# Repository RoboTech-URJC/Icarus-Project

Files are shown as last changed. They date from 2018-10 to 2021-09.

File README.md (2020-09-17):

# Drone Icarus

&nbsp;


&nbsp;


## Description

It is an autonomous drone which is able of avoiding obstacles and detecting other drones. The main functionality of this drone is being able to shoot down others drones on flight

## Contributions Guidelines

Do you want to contribute to our project? Check out our guidelines before you contribute: CONTRIBUTING

<p align="center">
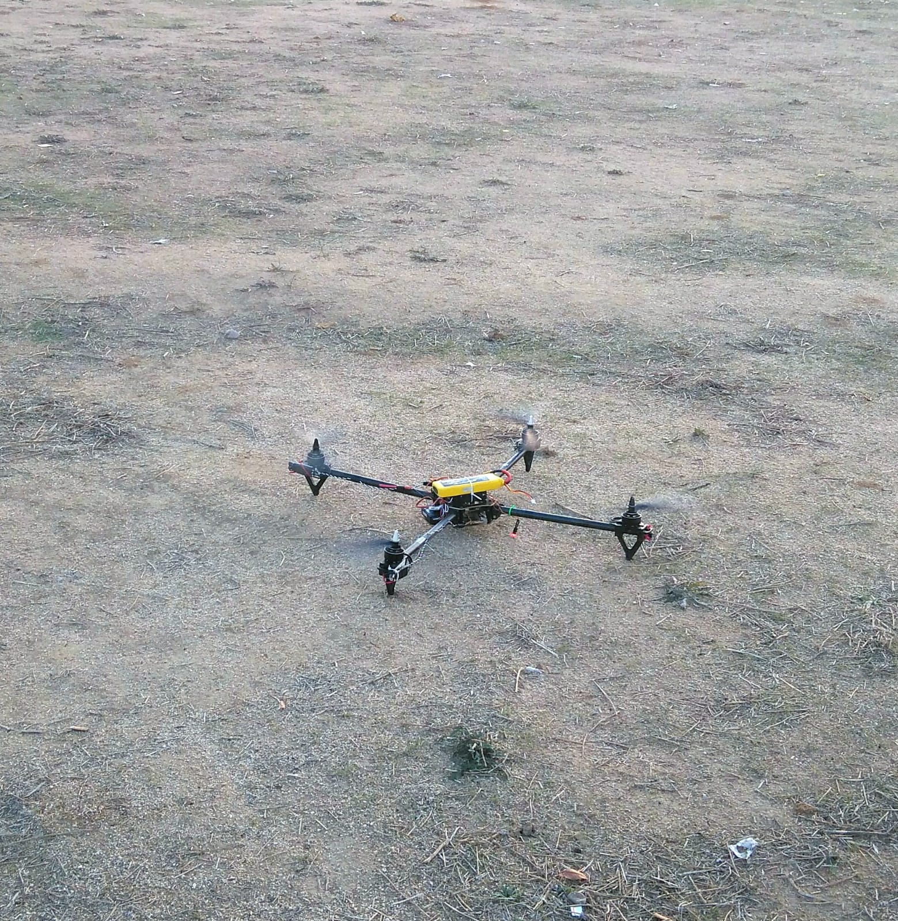
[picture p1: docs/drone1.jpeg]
  
</p>

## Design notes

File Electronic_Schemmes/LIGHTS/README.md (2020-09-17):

# Lights Controller

&nbsp;
&nbsp;

Lights controller has been complete designed for controlling 4 RGB LED raws by pairs (head and tail of the drone), in order to provide a better ground-air visualization  with our drone and know at real time what the drone is doing inside its hardware
### Hardware
Hardware consist of a PCB, 12 transistors **2N2222** , 12 resistors **2kOhm** and **Arduino Nano** which works as the semi-embedded micro-controller
### Software
The purpose of the controller mainly is to control with PWM signal (not implemented yet) the bright of led as well as create a code of colors which allow to controllers to verify what the drone is really doing on air. Programmed in Arduino (C++) the code drives the behavior of the lights through  the serial port.

:warning: Icarus driver method to comunicate with lights controller: `void IcarusDriver::notifyAck(std::string msg)`

Lights behaviors ~ parameter of notifyAck [`std::string msg`]:

- `a`: activate mode ~ green lights
- `b`: flying mode ~ blue lights
- `c`: warning mode ~ red lights
- `p`: pulse mode ~ flash lights --- to control the interval time of each flash change the variable `int pulse_interval`
- `s`: stop mode ~ turn off all lights

### Connections
 ARDUINO PIN | COLOR LED |
----------------------|-----------|
HEAD
3 | R |
5 | G |
6 | B |
TAIL
9 | R |
10 | G |
11 | B |

<p align="center">
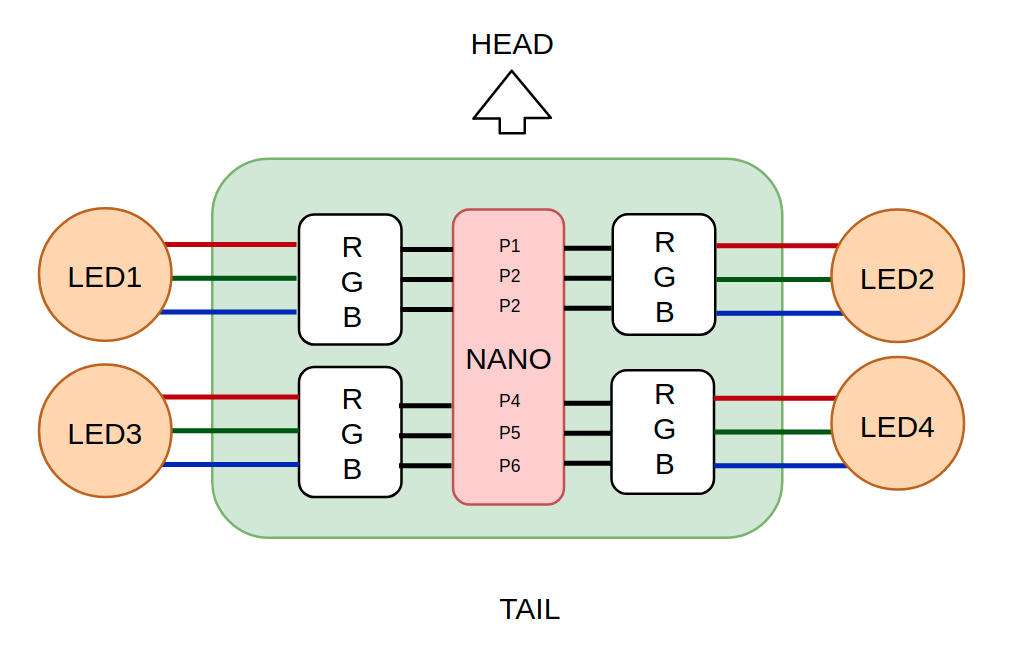
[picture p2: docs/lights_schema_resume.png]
  
</p>

 ### Designs

 - Schema

<p align="center">
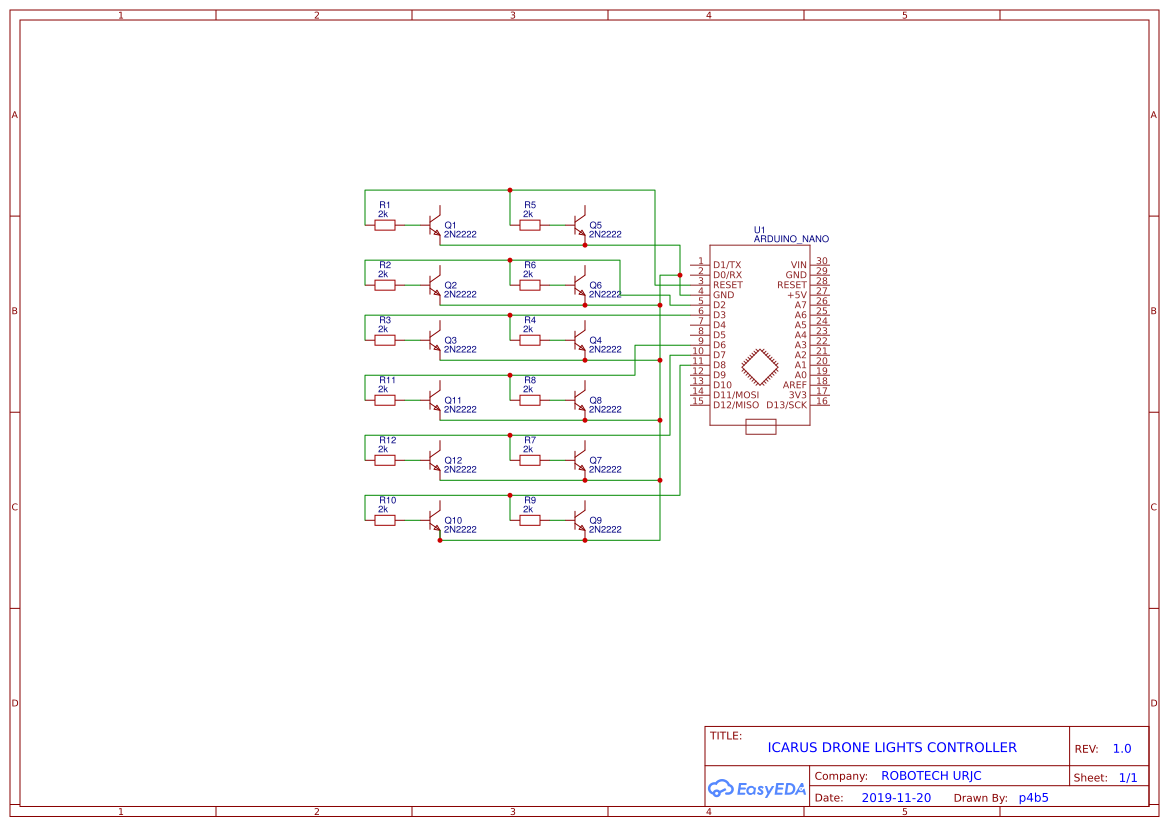
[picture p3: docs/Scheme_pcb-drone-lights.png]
  
</p>

- PCB layout

<p align="center">
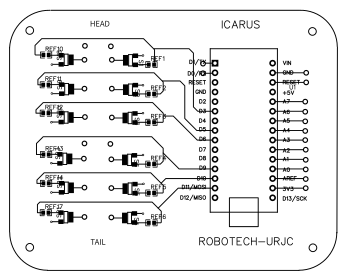
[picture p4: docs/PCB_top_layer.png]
  
</p>

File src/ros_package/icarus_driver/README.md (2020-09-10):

# ICARUS DRIVER

#### API of Icarus driver

| NAME  | DESCRIPTION | ACESS | FUNCTION |
| ---| --- | --- |--- |
| set mode  | set the mode you want to operate with the drone | `public` |`void IcarusDriver::SetMode(std::string mode)`|
| arm / disarm  | arm or disarm the drone | `public` |`void IcarusDriver::armDisarm(int arm)`|
| take off  | take off to a preorder altitude  |`public` | `void IcarusDriver::takeoff(double alt)`|
| move to local point  | move to a point in the local map | `public`|`void IcarusDriver::moveLocalTo(double x, double y,double z)`|
| turn to local point  | turn to a point in the local map | `public`|`IcarusDriver::void turnLocalTo(double roll, double pitch, double yaw);`|
| get status | get Icarus drone status |`public`|`StatusType IcarusDriver::getArmStatus()`|
| Init parameters | inicialization of parameters | `private`| `void IcarusDriver::initParams();`|
| ack notifier | notify an external serial port device |`private`|`void IcarusDriver::notifyAck(std::string msg)`|
| mavros state callback | notify an external serial port device |`private`|`void IcarusDriver::droneStateCb(const mavros_msgs::State::ConstPtr& msg);`|
| battery status callback | notify an external serial port device |`private`|`void IcarusDriver::batteryStatusCb(const sensor_msgs::BatteryState::ConstPtr& msg);`|

> TODO: emergency_land(), move_global_to(), watchdog()

#### Icarus Driver Types:

```
typedef struct StatusType StatusType;
struct StatusType
{
  bool is_armed;
  float battery_percentage;
};
```

# BOCANEGRA

Bocanegra is a state machine conceived specially for this project and addressed to give the best performace for our purpose.

<p align="center">
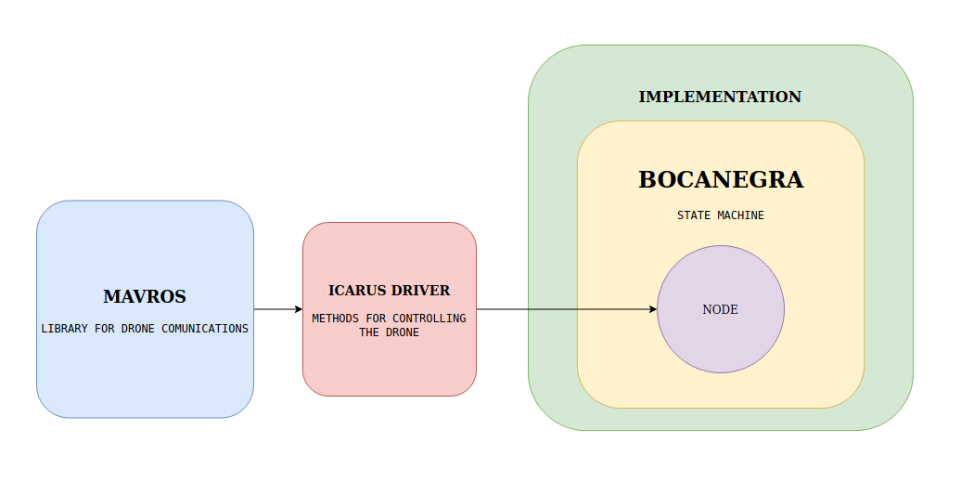
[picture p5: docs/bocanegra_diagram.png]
  
</p>

#### API of Bocanegra state machine driver

| NAME  | DESCRIPTION | ACESS | FUNCTION |
| ---| --- | --- |--- |
| is active | check if a node is active  | `protected` | `bool Bocanegra::isActive()` |
| activate  | active an inactivate node | `protected` | `void Bocanegra::activate(std::string node_name)`|
| deactivate  | deactivate a node | `protected` | `void Bocanegra::deactivate(std::string node_name)`|
| states callback | give the vector of states |`private`|`void Bocanegra::statesCallback(const boca_negra_msgs::states::ConstPtr msg)`|
| is active | check if a node is active  | `private` | `bool Bocanegra::isActive(std::string node_name)` |

#### Bocanegra messages

| NAME  | DESCRIPTION | MSGS |
| ---| --- | --- |
| state | msg with the node and its state |<p>`std_msgs/String node_name`</p> <p>`std_msgs/Bool is_active`</p>|
| states  | array with all the current node_states  | `state[] array`|

#### Bocanegra services

| NAME  | DESCRIPTION | SRV |
| ---| --- | --- |
| state_change | <p>request: node_name + state</p><p>response: node_name + new state</p>|<p>`std_msgs/String node_name`</p>`std_msgs/Bool active`<p>---</p><p>`std_msgs/String node_name`</p><p>`std_msgs/Bool active`</p>|

#### EXAMPLE

to begin to use our implementation, follow these steps:

 1. Run `~/Firmware/Tools/gazebo_sitl_multiple_run.sh -n 1`
 2. Run `roslaunch mavros px4.launch fcu_url:="udp://:14540@127.0.0.1:14557"`
 3. `roslaunch icarus_driver icarus_driver.launch`
 4. `rosrun simple_mover_drone hfsm_mover_node`

 optionally you can visualize:
 - rviz: `rosrun rviz rviz`
 - drone position: `rostopic echo /mavros/local_position/pose`

<p align="center">
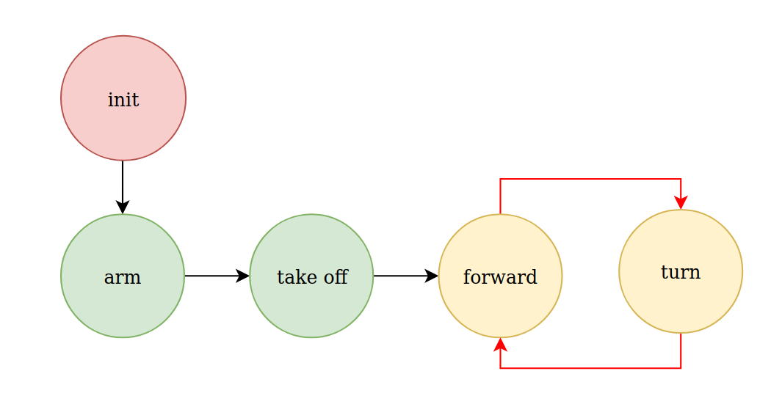
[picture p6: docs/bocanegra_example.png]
  
</p>

<p align="center">
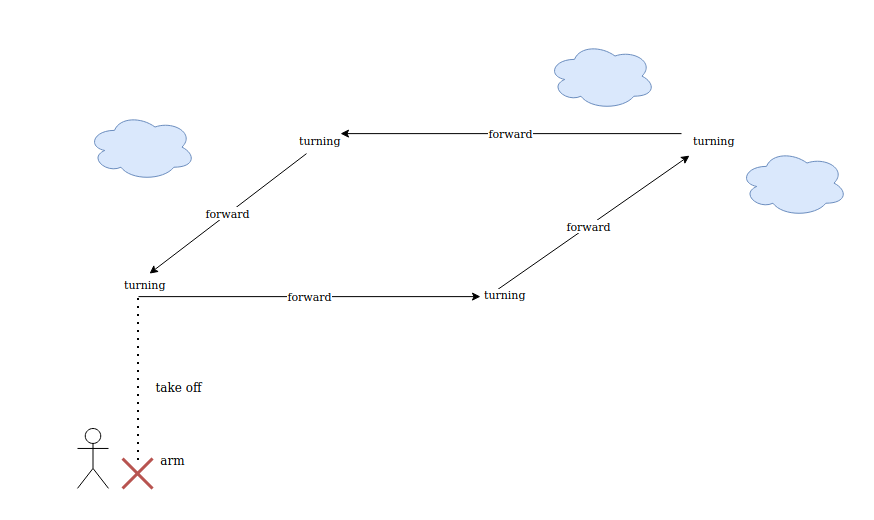
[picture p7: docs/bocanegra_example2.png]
  
</p>

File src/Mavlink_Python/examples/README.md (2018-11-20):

Here there are diferent example applications that uses the driver 'driver-icarus.py'.
* ["application1.py" demo:](https://www.youtube.com/watch?v=0h_9_rxgOh0&t=25s) Demostration with simulated drone.

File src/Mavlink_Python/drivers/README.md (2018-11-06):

# Description
It is about the driver that control all functionalities of Icarus

# Usage and Functionality of Main Methods
Here is explained the main methods used in the driver 'driver-icarus.py' included in pymavlink library.
## mavutil.mavlink_connection(port)
This method serves to open a serial, UDP, TCP or file mavlink connection, where "port" is the serial device or 
the UDP ot TCP end point. In each case, port value is:
* **Serial Device:** '/dev/ttyX'
* **End Point:** 'udpin:IP:Port' for UDP connection; or 'tcpin:IP:Port' for tcp connection. 
Example:
```
ardupilot = mavutil.mavlink_connection('udpin:localhost:14551')
```
This method can also receive more parameter that in case thay are not given, thay have a default value. The header of this method is the next one:
```
def mavlink_connection(device, baud=115200, source_system=255, source_component=0,
                       planner_format=None, write=False, append=False,
                       robust_parsing=True, notimestamps=False, input=True,
                       dialect=None, autoreconnect=False, zero_time_base=False,
                       retries=3, use_native=default_native,
                       force_connected=False, progress_callback=None):
```

## recv_match()
Receive the next MAVLink message. It can receive parameters or not. His header is the next one:
```
def recv_match(self, condition=None, type=None, blocking=False, timeout=None):
```
In this case, we use that method to receive the initial parameters of configuration of the drone. This type of message is called "HEARTBEATE", so, if we want to receive this parameter, the sentence to do this will be                                              
``msg = ardupilot.recv_match(type='HEARTBEAT', blocking=True)``. The parameter "blocking" serves to make that the call to this method blocking. 

## recv_msg()
Receive any message from the drone. Example:
```
msg = self.ardupilot.recv_msg()
print msg
```
We can put this code into a loop to read every time the messages the drone sends.

## mav.heartbeat_send()
This method is very important because it serves to coordinate the pc with the drone. That function send a hearbeat message to the drone of the samme way that drone sended it to us and we could to read it using the method "recv_match()" previously mentioned. It is very important that the parameters we send to the drone with this method are the same. The header of this methos is as follows:
```
self.ardupilot.mav.heartbeat_send(type, autopilot, base_mode, custom_mode, system_status, mavlink_version)
```
You can see which are these parameters using the previous function as follows:
```
msg = ardupilot.recv_match(type='HEARTBEAT', blocking=True)
print(msg)
```
## set_mode_apm(mode)
This method serves to set the flight mode of the drone to any of different modes that exist. That modes are:

| Mode | Summary |
| ---- | --- |
| Acro |  Holds attitude, no self-level |
| Alt Hold |  Holds altitude and self-levels the roll & pitch |
| Auto |  Executes pre-defined mission |
| AutoTune |  Executes pre-defined mission |
| Brake |  Brings copter to an immediate stop |
| Circle |  Automatically circles a point in front of the vehicle |
| Drift |  Like stabilize, but coordinates yaw with roll like a plane |
| Flip |  Rises and completes an automated flip |
| FlowHold |  Position control using Optical Flow |
| Follow |  Follows another vehicle |
| Guided |  Navigates to single points commanded by GCS |
| Land |  Reduces altitude to ground level, attempts to go straight down |
| Loiter |  Holds altitude and position, uses GPS for movements |
| PosHold |  Like loiter, but manual roll and pitch when sticks not centered |
| RTL |  Retruns above takeoff location, may aslo include landing |
| SmartRTL |  RTL, but traces path to get home |
| Stabilize |  Self-levels the roll and pitch axis |
| Sport |  Alt-hold, but holds pitch & roll when sticks centered |
| Throw |  Holds position after a throwing takeoff |

For example, to change to "Guided" mode: ``ardupilot.set_mode_apm('GUIDED')`` .

## mav.command_long_send()
Serves to send commands to the drone. The parameters that it receives depend of the command type. [Here](http://ardupilot.org/planner/docs/common-mavlink-mission-command-messages-mav_cmd.html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) are every commands and his usability

# How to Receive Parameters?
To receive parameters we use ``messages[[Param type]].[match]``. For example, if we want to receive the relative altitude of the drone, we will use ``ardupilot.messages['GLOBAL_POSITION_INT'].relative_alt``

How can we know which is the param type we have tu use? We can see all the parameters that the drone sends with ``recv_msg`` inside a loop. that is an example of we receive:
```
RAW_IMU {time_usec : 2420564594, xacc : 0, yacc : 0, zacc : -1001, xgyro : 1, ygyro : 1, zgyro : 1, xmag : 194, ymag : 118, zmag : -538}
SCALED_IMU2 {time_boot_ms : 32485335, xacc : 0, yacc : 0, zacc : -1001, xgyro : 1, ygyro : 1, zgyro : 1, xmag : 194, ymag : 118, zmag : -538}
SCALED_PRESSURE {time_boot_ms : 32485335, press_abs : 945.027038574, press_diff : 0.0, temperature : 3500}
SYS_STATUS {onboard_control_sensors_present : 56753199, onboard_control_sensors_enabled : 39975983, onboard_control_sensors_health : 56753199, load : 0, voltage_battery : 12587, current_battery : 0, battery_remaining : 83, drop_rate_comm : 0, errors_comm : 0, errors_count1 : 0, errors_count2 : 0, errors_count3 : 0, errors_count4 : 0}
POWER_STATUS {Vcc : 5000, Vservo : 0, flags : 0}
MEMINFO {brkval : 0, freemem : 65535, freemem32 : 131072}
MISSION_CURRENT {seq : 0}
GPS_RAW_INT {time_usec : 32485215000, fix_type : 6, lat : -353632564, lon : 1491652320, alt : 584100, eph : 121, epv : 200, vel : 0, cog : 11789, satellites_visible : 10, alt_ellipsoid : 0, h_acc : 200, v_acc : 200, vel_acc : 40, hdg_acc : 0}
NAV_CONTROLLER_OUTPUT {nav_roll : -0.119866870344, nav_pitch : -0.117011599243, nav_bearing : -22, target_bearing : 0, wp_dist : 0, alt_error : -0.657050848007, aspd_error : 0.0, xtrack_error : 0.0}
GLOBAL_POSITION_INT {time_boot_ms : 32485335, lat : -353632563, lon : 1491652315, alt : 584010, relative_alt : 6, vx : 1, vy : -4, vz : 0, hdg : 33785}
LOCAL_POSITION_NED {time_boot_ms : 32485335, x : -0.0935497283936, y : 0.259233921766, z : -0.00685916794464, vx : 0.0173883810639, vy : -0.0487783513963, vz : 0.00074397190474}
SERVO_OUTPUT_RAW {time_usec : 2420564594, port : 0, servo1_raw : 1000, servo2_raw : 1000, servo3_raw : 1000, servo4_raw : 1000, servo5_raw : 0, servo6_raw : 0, servo7_raw : 0, servo8_raw : 0, servo9_raw : 0, servo10_raw : 0, servo11_raw : 0, servo12_raw : 0, servo13_raw : 0, servo14_raw : 0, servo15_raw : 0, servo16_raw : 0}
RC_CHANNELS {time_boot_ms : 32485335, chancount : 16, chan1_raw : 1500, chan2_raw : 1500, chan3_raw : 1000, chan4_raw : 1500, chan5_raw : 1800, chan6_raw : 1000, chan7_raw : 1000, chan8_raw : 1800, chan9_raw : 0, chan10_raw : 0, chan11_raw : 0, chan12_raw : 0, chan13_raw : 0, chan14_raw : 0, chan15_raw : 0, chan16_raw : 0, chan17_raw : 0, chan18_raw : 0, rssi : 0}
ATTITUDE {time_boot_ms : 32485335, roll : -0.00209207204171, pitch : -0.00204223790206, yaw : -0.386602848768, rollspeed : -0.000276305130683, pitchspeed : -0.000244989059865, yawspeed : -0.000729398336262}
SIMSTATE {roll : 0.0, pitch : 0.0, yaw : -0.341762781143, xacc : -2.19979159888e-10, yacc : 2.11345663192e-10, zacc : -9.80665016174, xgyro : -8.40779078595e-43, ygyro : -7.28675201449e-43, zgyro : 1.43051111081e-05, lat : -353632564, lng : 1491652320}
AHRS2 {roll : 0.00179860368371, pitch : 0.00161452894099, yaw : -0.345547944307, altitude : 0.0, lat : 0, lng : 0}
AHRS3 {roll : -0.00209207204171, pitch : -0.00204223790206, yaw : -0.386602848768, altitude : 584.010009766, lat : -353632563, lng : 1491652315, v1 : 0.0, v2 : 0.0, v3 : 0.0, v4 : 0.0}
VFR_HUD {airspeed : 0.0, groundspeed : 0.0517849698663, heading : 337, throttle : 0, alt : 584.010009766, climb : -0.00074397190474}
AHRS {omegaIx : -0.00153755501378, omegaIy : -0.00152305862866, omegaIz : -0.00194238708355, accel_weight : 0.0, renorm_val : 0.0, error_rp : 0.00235023279674, error_yaw : 0.00180114735849}
HWSTATUS {Vcc : 5000, I2Cerr : 0}
SYSTEM_TIME {time_unix_usec : 1541471159699221, time_boot_ms : 32485335}
TERRAIN_REPORT {lat : -353632563, lon : 1491652315, spacing : 100, terrain_height : 583.887329102, current_height : 0.0015869140625, pending : 0, loaded : 504}
BATTERY_STATUS {id : 0, battery_function : 0, type : 0, temperature : 32767, voltages : [12587, 65535, 65535, 65535, 65535, 65535, 65535, 65535, 65535, 65535], current_battery : 0, current_consumed : 144186, energy_consumed : 63240, battery_remaining : 83, time_remaining : 0, charge_state : 0}
```

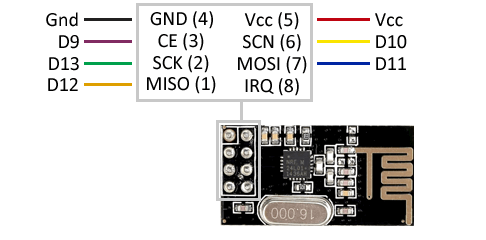
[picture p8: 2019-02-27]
Jammer/nrf24_pinout.png

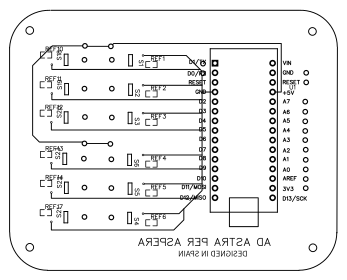
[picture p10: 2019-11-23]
docs/PCB_bottom_layer.png

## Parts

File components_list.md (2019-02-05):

| Component | Rate | Link | 
| --- | ---- | ---- |
| Orange Pi 3 | 41.05 € | [Aliexpress](https://es.aliexpress.com/store/product/Orange-Pi-3-H6-2GB-LPDDR3-8GB-EMMC-Flash-Gigabyte-Ethernet-Port-AP6256-WIFI-BT5-0/1553371_32971639306.html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,searchweb201602_2_10065_10068_10547_319_10891_317_10548_10696_10084_453_454_10083_10618_10307_10820_10821_10301_10303_537_536_10902_10059_10884_10887_321_322_10103-10891,searchweb201603_51,ppcSwitch_0&algo_expid=5c913c3a-22a4-4755-92a3-86eff891546d-0&algo_pvid=5c913c3a-22a4-4755-92a3-86eff891546d&transAbTest=ae803_4) |
| LiPo Battery | 40 € | [Amazon](https://www.amazon.es/HRB-Multicopteros-Helic%C3%B3pteros-Veh%C3%ADculo-Diversos/dp/B071GNLMPQ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) |
| GPS Antenna | 14.99 € | [Amazon](https://www.amazon.es/loonBonnie-Br%C3%BAjula-Controlador-Multicopter-Quadcopter/dp/B07M9W2NXG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) |

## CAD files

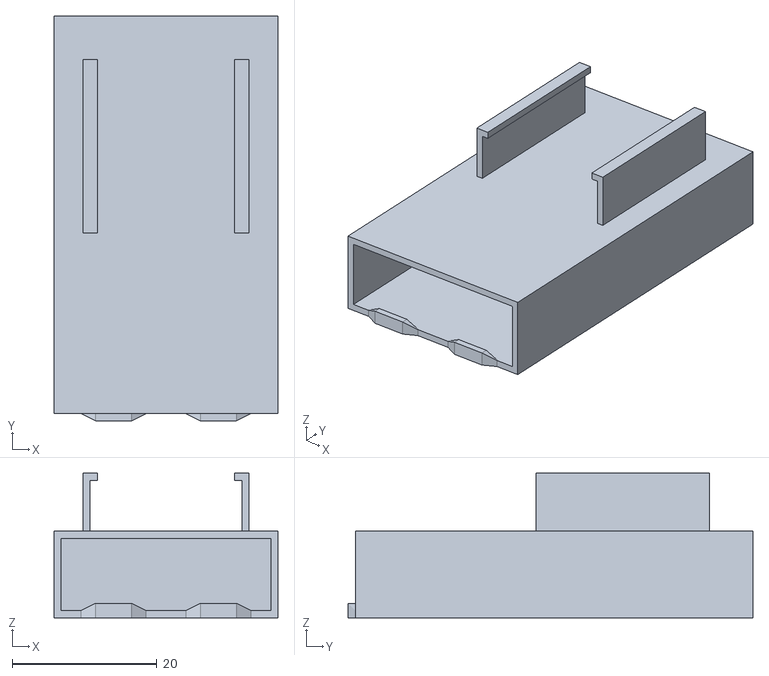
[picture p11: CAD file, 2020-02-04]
3D_print/drone_battery_holder.stl
31.0 x 56.0 x 20.0

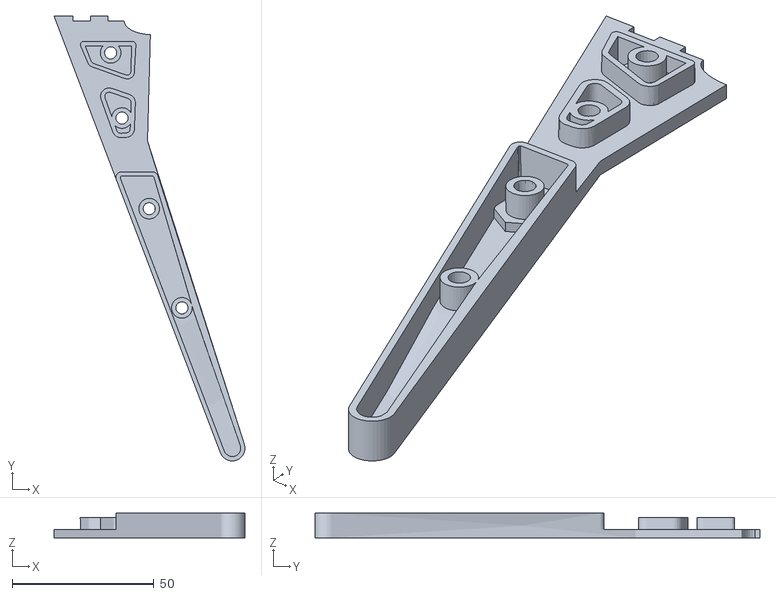
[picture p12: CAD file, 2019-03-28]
3D_print/landing gear/f550_Legs_Final.stl
67.4 x 157.0 x 8.70

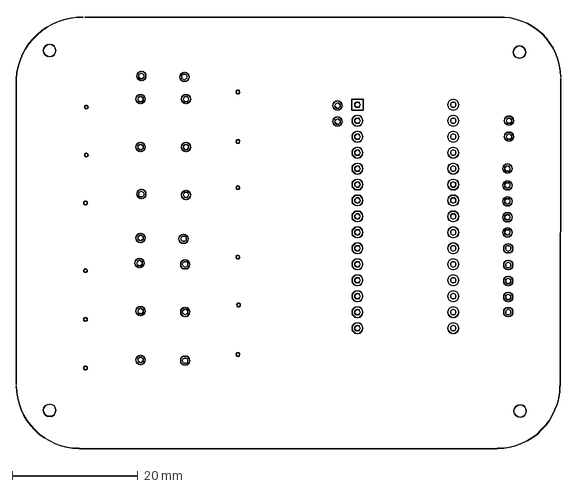
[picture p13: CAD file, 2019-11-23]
Electronic_Schemmes/LIGHTS/PCB/PCB_drone_lights.dxf
86.7 x 68.8 mm

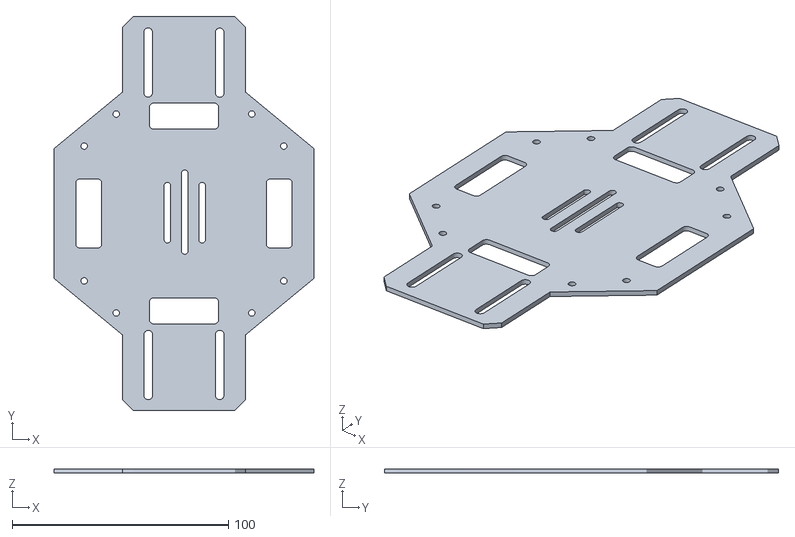
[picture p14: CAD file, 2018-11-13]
3D_print/bottom_plate.stl
120.0 x 182.0 x 2.00

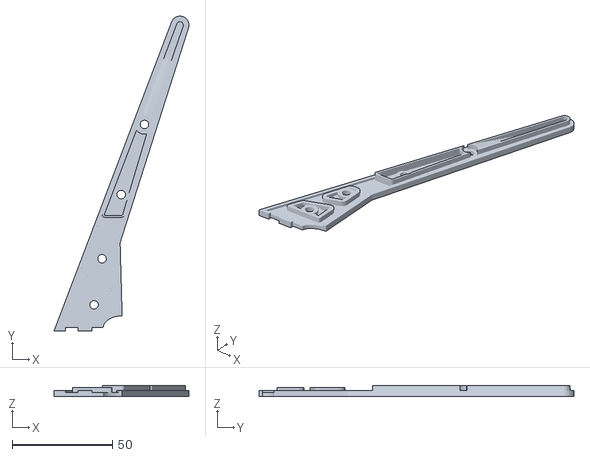
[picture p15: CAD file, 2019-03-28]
3D_print/landing gear/f550_legs_p2_final.stl
67.4 x 157.1 x 5.50

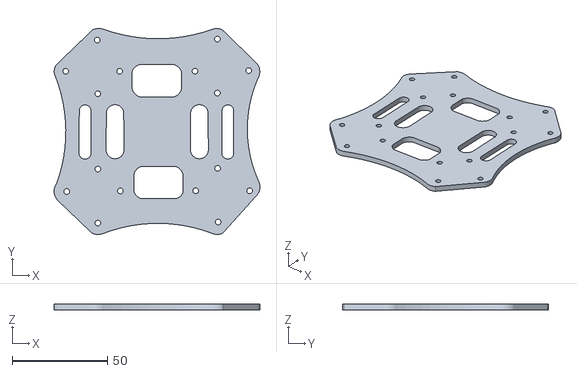
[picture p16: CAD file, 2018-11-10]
3D_print/top_plate.stl
108.2 x 108.2 x 3.00

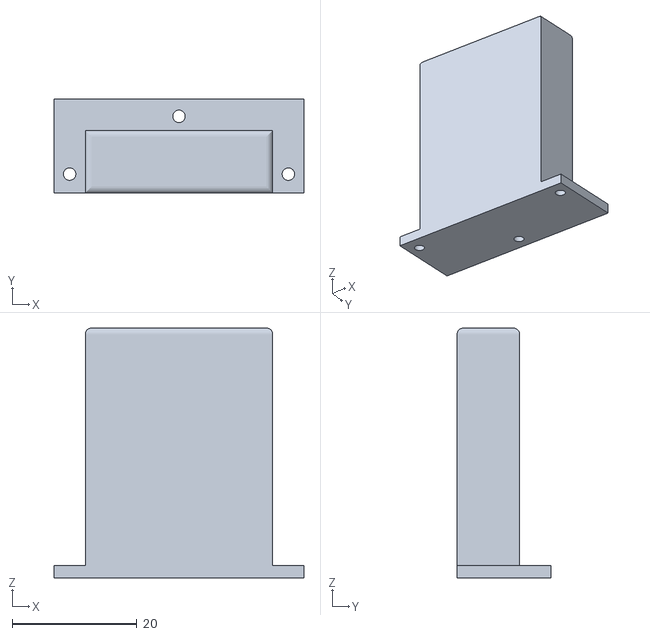
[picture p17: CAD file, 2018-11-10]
3D_print/big_extensor.stl
40.0 x 15.0 x 40.0

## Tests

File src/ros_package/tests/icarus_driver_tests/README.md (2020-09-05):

# Test Packages

First of all, before to try any of these trial packages, you have to run ``roslaunch icarus_driver icarus_driver.launch`` and gazebo simulation whose instructions are available [here](https://github.com/RoboTech-URJC/Icarus-Project/blob/master/src/ros_package/README.md).

## up_down

### Description

**TAKE OFF** - **LAND**  ICARUS DRIVER EXAMPLE.

This is a simple example to test the state machine and their methods in an easy way.

#### Methods used:

* armDisarm()
* takeoff()
* land()

> consult Icarus driver documentation for more info about methods

### Nodes

* **up_down_node:** The drone armed, take off, reach the max high assigned and land. This example is not iterative so the drone take off, land and finish its task.

<p align="center">
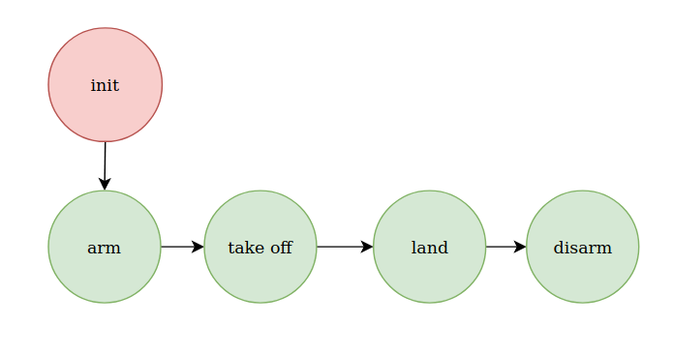
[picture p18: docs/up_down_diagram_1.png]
  
</p>

<p align="center">
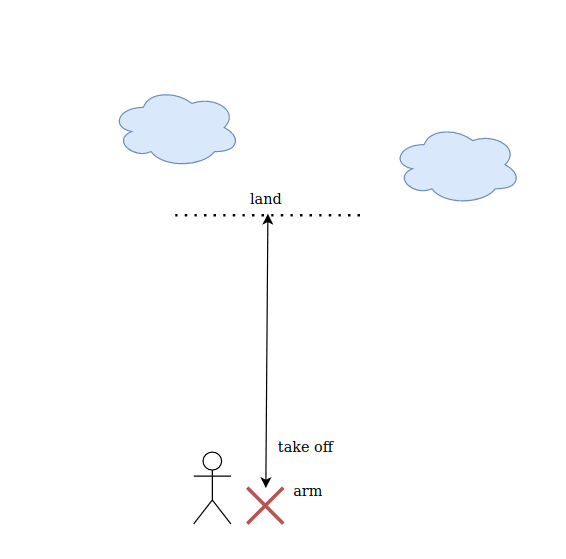
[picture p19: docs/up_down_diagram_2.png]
  
</p>

Click [here](https://www.youtube.com/watch?v=18O6sHyMoOc&feature=youtu.be) to see a demo.

## simple_mover_drone

### Desciption

This is a trial package used for *icarus_driver* testing. Local movement-related methods are tested.

#### Methods used:

* armDisarm()
* takeoff()
* moveLocalTo()
* turnLocalTo()
* land()

### Nodes

* **hfsm_mover_node:** Arm drone, takeoff, it makes a square and later it lands and the drone is disarmed.

The following states machine is used:

<p align="center">
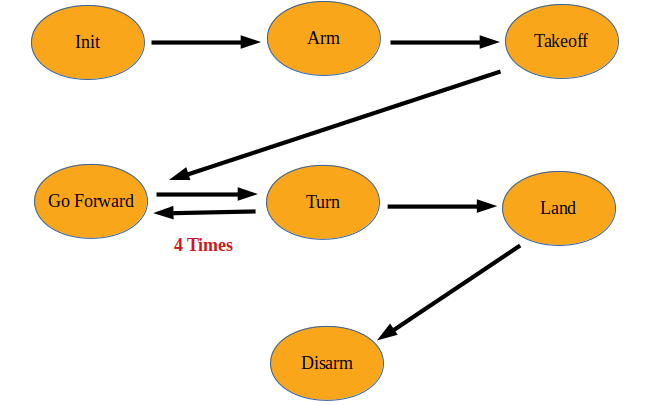
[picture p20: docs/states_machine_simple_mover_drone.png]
  
</p>

Click [here](https://www.youtube.com/watch?v=8j3A2Or808Q&feature=youtu.be) to see a demo.

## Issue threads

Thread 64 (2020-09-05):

[Icarus-Driver] isArmed() method

P4B5, 2020-09-05:
It's necessary to create new method to know if the drone is armed or not

P4B5, 2020-09-10:
this issue has been resolved at #71 PR

Closed 2020-09-10.

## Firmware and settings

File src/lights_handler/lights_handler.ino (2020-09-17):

class Lights
{
public:
  Lights()
  {
  // head lights

    Lights::red_led_head = 3;
    Lights::green_led_head = 5;
    Lights::blue_led_head = 6;

    // tail lights

    Lights::red_led_tail = 9;
    Lights::green_led_tail = 10;
    Lights::blue_led_tail = 11;

    Lights::set_leds();
  }

  void
  run(char state){

    switch (state) {

      // activate/arm mode = green lights:

      case 'a':
        Lights::turn_off(Lights::red_led_head);
        Lights::turn_on(Lights::green_led_head);
        Lights::turn_off(Lights::blue_led_head);

        Lights::turn_off(Lights::red_led_tail);
        Lights::turn_on(Lights::green_led_tail);
        Lights::turn_off(Lights::blue_led_tail);

      break;

      // flying mode = blue lights:

      case 'b':
        Lights::turn_on(Lights::red_led_head);
        Lights::turn_off(Lights::green_led_head);
        Lights::turn_off(Lights::blue_led_head);

        Lights::turn_on(Lights::red_led_tail);
        Lights::turn_off(Lights::green_led_tail);
        Lights::turn_off(Lights::blue_led_tail);

        break;

      // warning =  red lights:

      case 'c':
        Lights::turn_on(Lights::blue_led_head);
        Lights::turn_off(Lights::red_led_head);
        Lights::turn_off(Lights::green_led_head);

        Lights::turn_on(Lights::blue_led_tail);
        Lights::turn_off(Lights::red_led_tail);
        Lights::turn_off(Lights::green_led_tail);

        break;

      // pulse = flash lights:

      case 'p':
        Lights::turn_off(Lights::red_led_head);
        Lights::turn_off(Lights::green_led_head);
        Lights::turn_off(Lights::blue_led_head);

        Lights::turn_off(Lights::red_led_tail);
        Lights::turn_off(Lights::green_led_tail);
        Lights::turn_off(Lights::blue_led_tail);

        Lights::blink_led(Lights::blue_led_head, pulse_interval);

        break;

      case 's':  // stop = turn off all lights
        Lights::turn_off(Lights::red_led_head);
        Lights::turn_off(Lights::green_led_head);
        Lights::turn_off(Lights::blue_led_head);

        Lights::turn_off(Lights::red_led_tail);
        Lights::turn_off(Lights::green_led_tail);
        Lights::turn_off(Lights::blue_led_tail);

        break;
    }
  }

  void
  sleep(unsigned long t0, float freq)
  {
    int dead_time;
    unsigned long tf, elapsed;
    tf = millis();
    elapsed = tf - t0;
    dead_time = (int) ((1.0 / freq) - elapsed);
    if(dead_time > 0){
      delay(dead_time);
    }
  }

private:
  int red_led_head;
  int green_led_head;
  int blue_led_head;

  int red_led_tail;
  int green_led_tail;
  int blue_led_tail;

  // interval of the flashing lights:

  int pulse_interval = 2;

  // current status of lights:

  char lights_status;

  void
  set_leds()
  {
    pinMode(Lights::red_led_head, OUTPUT);
    pinMode(Lights::green_led_head, OUTPUT);
    pinMode(Lights::blue_led_head, OUTPUT);

    pinMode(Lights::red_led_tail, OUTPUT);
    pinMode(Lights::green_led_tail, OUTPUT);
    pinMode(Lights::blue_led_tail, OUTPUT);
  }

  void
  turn_off(int pin_out)
  {
    digitalWrite(pin_out, LOW);
  }

  void
  turn_on(int pin_out)
  {
    digitalWrite(pin_out, HIGH);
  }

  void
  blink_led(int pin_out, float hertz)
  {
    float interval = (1.0 / hertz) * 1000.0;

    turn_on(pin_out);
    delay(interval);

    turn_off(pin_out);
    delay(interval);
  }
};

Lights lights;

void
setup()
{
  Serial.begin(9600);
}

char state = ' ';
unsigned long t0;

void
loop()
{
  /*
   * Implements reactive algorithm
   */

  // read state:

  t0 = millis();
  state = Serial.read();

  // Serial.println(state);

  // exec state:

  lights.run(state);
  lights.sleep(t0, 12.0);
}

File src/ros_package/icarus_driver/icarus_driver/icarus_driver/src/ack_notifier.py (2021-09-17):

#! /usr/bin/env python

import rospy
from std_msgs.msg import String

import serial
import os

# Global variable:

NodeName = 'ack_notifier_node'


class Notifier():
    def __init__(self):
        self.ser_ = None
        self.port_ = None

        self.init_params()

        rospy.Subscriber('/icarus_driver/ack_notify', String, self.callback)

    def init_params(self):

        self.port_ = rospy.get_param('~arduino_port', '/dev/ttyACM0')
        baudrate = rospy.get_param('~baudrate', '9600')
        try:
            self.ser_ = serial.Serial(self.port_, baudrate)
        except serial.serialutil.SerialException:
            self.raise_except()

    def callback(self, data):
        # b = bytes(data.data)

        self.ser_.write(data.data)

    def raise_except(self):
        rospy.logerr("[%s] Ligths Handler Serial Port could not be opened\n", self.port_)
        os.system("rosnode kill " + NodeName)


if __name__ == "__main__":

    rospy.init_node(NodeName)

    rate = rospy.Rate(10)   # 10 Hz
    try:

        notifier = Notifier()
        rospy.spin()

    except KeyboardInterrupt:
        pass

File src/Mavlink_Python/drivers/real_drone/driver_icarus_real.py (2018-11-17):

#!/usr/bin/env python
# -*- coding: utf-8 -*-

import time
from pymavlink import mavutil
import sys

class Drone:
    def __init__(self, port):
        '''
        Port is where drone is listening. As UDP or TCP as Serial
        '''
        #To create la conection:
        self.ardupilot = mavutil.mavlink_connection(port, baud=57600) #Open the connection

        #Parameters:
        self.ardupilot_sys_id = self.ardupilot.target_system
        self.ardupilot_component_id = self.ardupilot.target_component

        self.wait_heartbeat() #prints the initial parameters of the drone

        self.ardupilot.mav.heartbeat_send(
        2, # type
        3, # autopilot
        81, # base_mode
        0, # custom_mode
        3, # system_status
        3  # mavlink_version
        )


        self.change_mode('STABILIZE')

    #HERE STARTS THE MAIN METHODS

    def arm_disarm(self, state, failsafe):
        '''
        arm or disarm the drone depending of the parameter state:
        if state = 1, then arm drone;
        if state = 0, then disarm drone;
        if state != 0 and state != 1, return a message of error
        failsafe == 1 serves to disarm the drone on flight
        '''
        def is_correct(n):
            return n == 0 or n == 1

        if(is_correct(state) and is_correct(failsafe)):
            '''
            while(True):
                msg = None
                while(msg == None):
                    msg = self.ardupilot.recv()

                print(msg)
            '''
            self.ardupilot.mav.command_long_send(self.ardupilot_sys_id,
                                            self.ardupilot_component_id,
                                            mavutil.mavlink.MAV_CMD_COMPONENT_ARM_DISARM,
                                            0, #confirmation
                                            state, failsafe, 0, 0, 0, 0, 0)
            #self.ardupilot.write(buf)

            #self.ardupilot.arducopter_arm()

            if(state == 1):
                #wait to arm
                self.ardupilot.motors_armed_wait()
                #self.ardupilot.write(buf)
            elif(state == 0):
                #wait to disarm
                self.ardupilot.motors_disarmed_wait()

        else:
            print("[USAGE ERROR] state value is 1 or 0 for arm/disarm the drone")
            print("failsafe value is 1/0 for disarm or not disarm the drone on flight")

    def takeoff(self, altitude):
        '''
        Take off the drone to a specific altitude
        '''

        def wait_to_takeoff():

            error_range = 0.08
            alt = self.get_alt()
            while(alt < altitude - error_range):
                alt = self.get_alt()
                print(alt)

        #self.change_mode('AUTO') # set mode flight

        self.ardupilot.mav.command_long_send(self.ardupilot_sys_id,
                                        self.ardupilot_component_id,
                                        mavutil.mavlink.MAV_CMD_NAV_TAKEOFF,
                                        0, #confirmation
                                        0, 0, 0, 0, 0, 0, altitude)

        '''
        #self.ardupilot.write(buf)
        while(True):
            msg = None
            while(msg == None):
                msg = self.ardupilot.recv_match()
            print(msg)
        #time.sleep(2)
        '''
        wait_to_takeoff() #Block the method while drone is taking off

    def land(self):
        '''
        Land the drone
        '''

        def wait_to_land():

            error_range = 0.08

            alt = self.get_alt()
            while(alt > error_range):
                alt = self.get_alt()

        self.change_mode('LAND')
        wait_to_land() #Block the method while drone is landing

    #HERE STARTS THE SECONDARY METHODS

    def get_alt(self):
        '''
        Returns the altitude in meters
        '''

        param = self.ardupilot.recv_match(type='GLOBAL_POSITION_INT', blocking = True) #receive all parameters
        alt = param.relative_alt * 0.001
        return alt

    def change_mode(self, mode):
        '''
        Change the flight mode
        '''

        self.ardupilot.set_mode_apm(mode) # set mode flight
        print("Mode changed to " + mode)

    def wait_heartbeat(self):
        '''
        wait for a heartbeat so we know the target system IDs
        '''

        print("Waiting for APM heartbeat")
        msg = self.ardupilot.recv_match(type='HEARTBEAT', blocking=True)
        print(msg)
        #self.ardupilot.pre_message()
        #print(self.ardupilot.location())
        print("Heartbeat from APM (system %u component %u)" % (self.ardupilot.target_system,
                                                                    self.ardupilot.target_component))

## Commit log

2018-11-10 Create 3D print
2018-11-15 commit de prueba
2018-11-17 name of folder "3D print" changed
    [big_extensor.stl, bottom_plate.stl, top_plate.stl]
2018-11-17 [drivers]Uploaded driver for real drone
2018-11-20 esta es una modificacion de prueba
2019-01-30 Folder with LED PCB board designed inside it
    [Led_board.fzz, Led_pcb.fzz]
2019-02-25 update lights
    [Led_board.fzz, Led_pcb.fzz]
2019-02-25 [PCB] redefined directories system of electronic schemes
    [Led_board.fzz, Led_pcb.fzz]
2019-02-27 [Jammer] Scanning code to discover which channels have been used
    [scanner.ino]
2019-02-27 NRF24 pinout schematic added
2019-09-23 [driver refactoring]ros package added
2019-09-27 [driver] new methods added
2019-10-10 [lights handler] Arduino code added
2019-10-10 arduino code changes
2019-11-22 lights controller updated
    [Led_board.fzz, Led_pcb.fzz, PCB_drone_lights.dxf]
2019-11-22 schemme pcb updated
2020-02-04 Add files via upload
    battey holder stl
    [drone_battery_holder.stl]
2020-08-17 [local_mover.cpp]node finished and driver updated
2020-08-28 new README for drivers
2020-08-29 documentation for icarus driver and bocanegra
2020-09-02 landing example
2020-09-04 documentation for up_down Icarus driver example
2020-09-05 isArmed + batteryStatus methods added
2020-09-22 Added Easy Eda PCB file

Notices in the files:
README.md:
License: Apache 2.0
